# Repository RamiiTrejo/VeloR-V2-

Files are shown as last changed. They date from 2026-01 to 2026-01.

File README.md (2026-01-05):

## VeloR-V2

 Velo será un Robot seguidor de Líneas con una turbina integrada para una mayor agilidad, tambien llevara una regleta de 16 Sensores QRE1113, para una mejor lectura de la pista para lograr competir en la categoria de Carreras Pro de la LNR

<table>
<tr>
<td  colspan="2">  </td>
</tr>
<tr>
<td> 
 </td>
<td> 
 </td>
</tr>
</table>

## 🛠️🧰COMPONENTES
los componentes que utilizara este robot son
- ESP32 embebido
- Motores profast de 3600 RPM
- Ruedas JS2124
- Puentes H TA6586
- Motor Brushless/Coreless como Turbina
- Regleta De 16 [sensores QRE1113](https://github.com/RamiiTrejo/Array-16-Sensors)

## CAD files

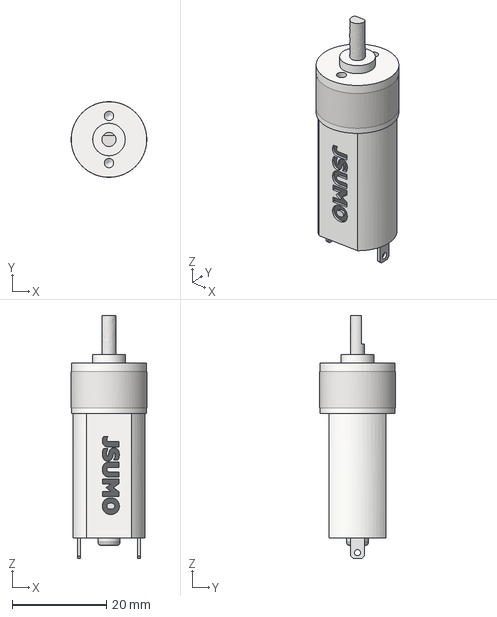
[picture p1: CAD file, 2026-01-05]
Hardware veloR V2/3d Files VeloR/Profast-dc-motor.igs
16.0 x 16.0 x 51.5 mm

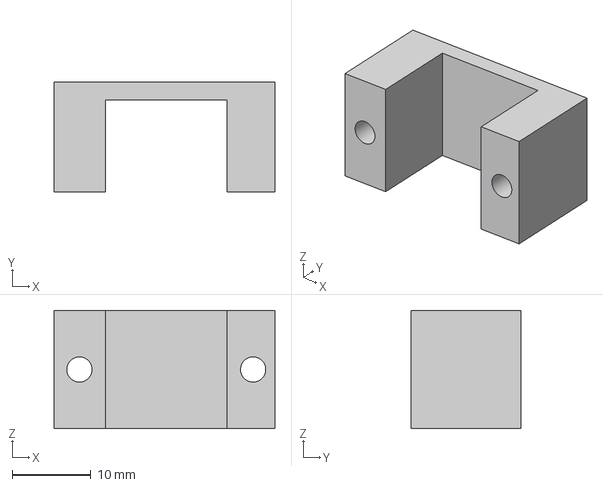
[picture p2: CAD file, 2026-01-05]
Hardware veloR V2/3d Files VeloR/bracket profast 3600rpm.step
28.1 x 14.0 x 15.0 mm

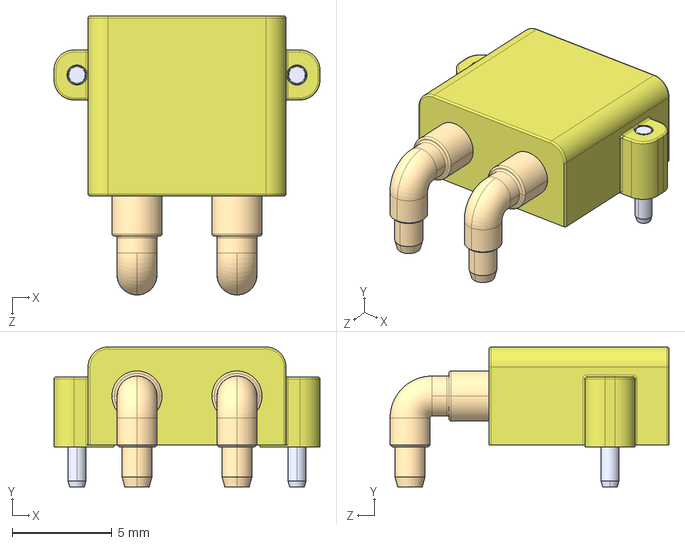
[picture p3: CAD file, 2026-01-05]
Hardware veloR V2/3d Files VeloR/XT30PW-M.step
13.3 x 7.00 x 14.0 mm

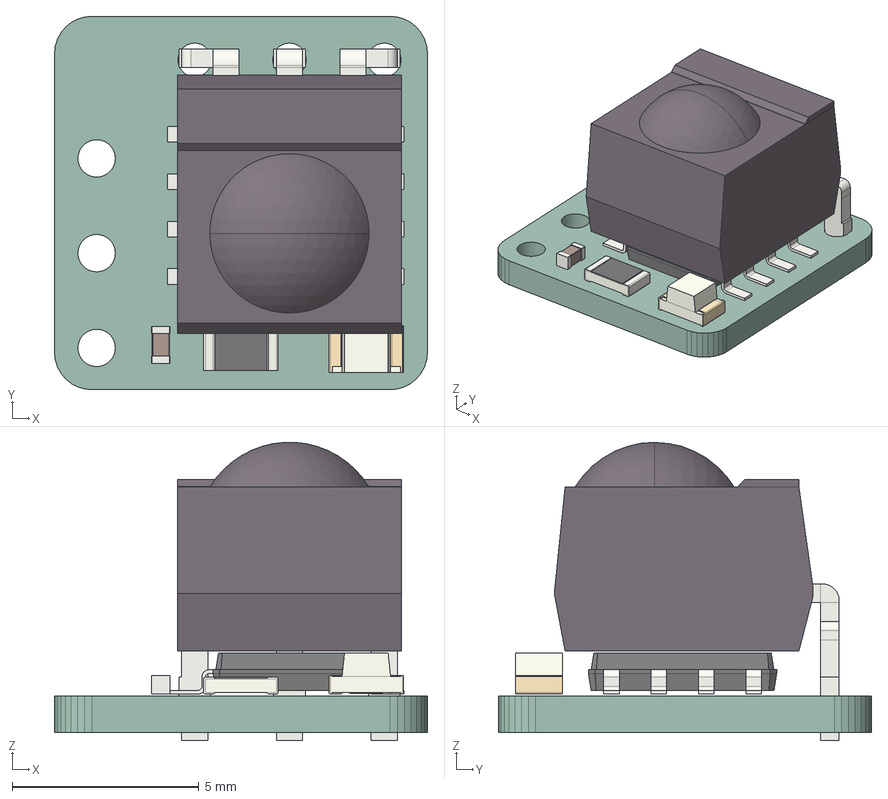
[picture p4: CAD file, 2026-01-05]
Hardware veloR V2/3d Files VeloR/IRStart - Module.step
10.0 x 10.0 x 8.00 mm
PCB

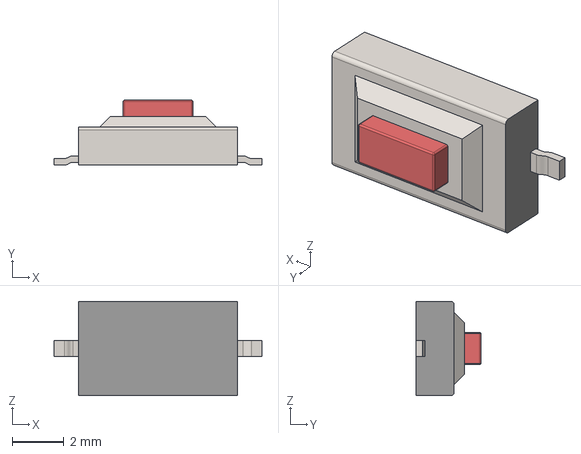
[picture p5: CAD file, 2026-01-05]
Hardware veloR V2/3d Files VeloR/BTN_SMD_3x6x2.5mm.step
8.05 x 2.51 x 3.66 mm

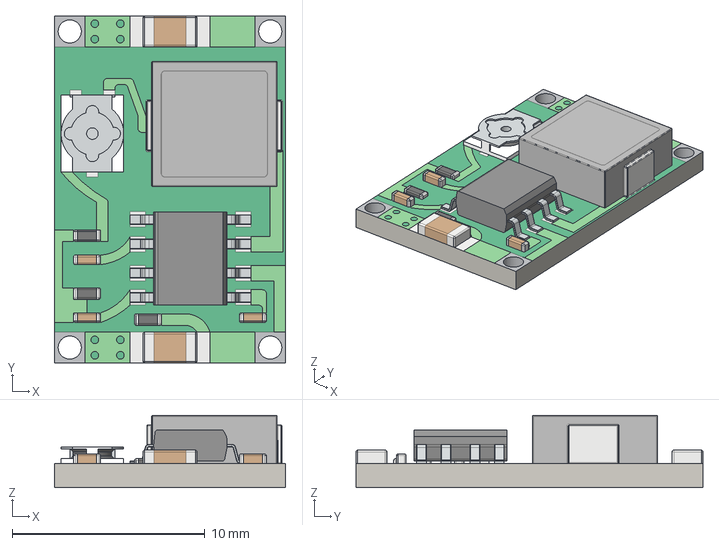
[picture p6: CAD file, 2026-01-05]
Hardware veloR V2/3d Files VeloR/Mini360.step
12.0 x 18.0 x 3.75 mm

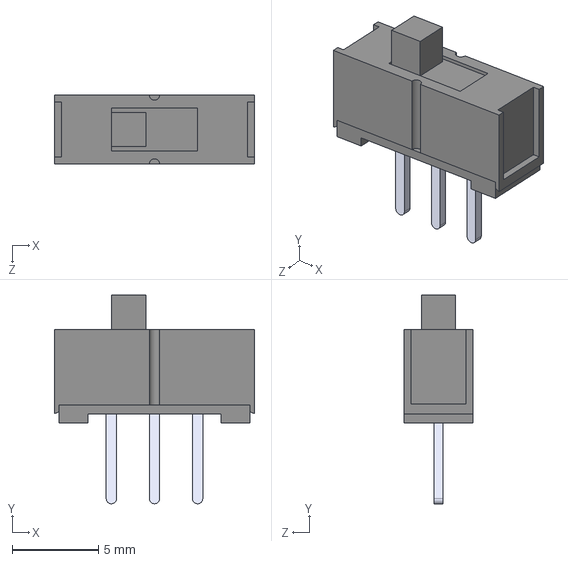
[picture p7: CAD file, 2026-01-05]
Hardware veloR V2/3d Files VeloR/MINI-SPDT-SW--3DModel-STEP-56544.STEP
11.6 x 12.1 x 4.00 mm

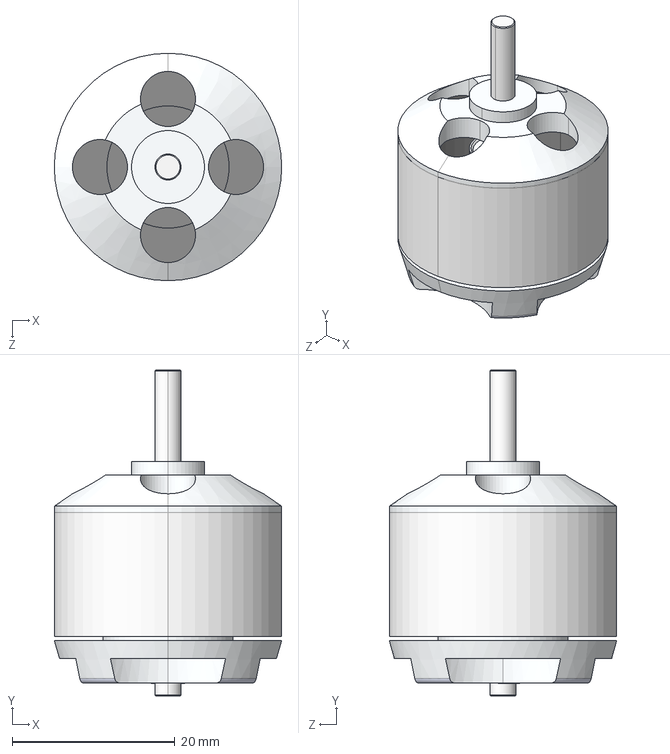
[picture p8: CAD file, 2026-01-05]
Hardware veloR V2/3d Files VeloR/Motor_BLDC_2212,6T_2200KV.STEP
27.9 x 40.0 x 27.9 mm

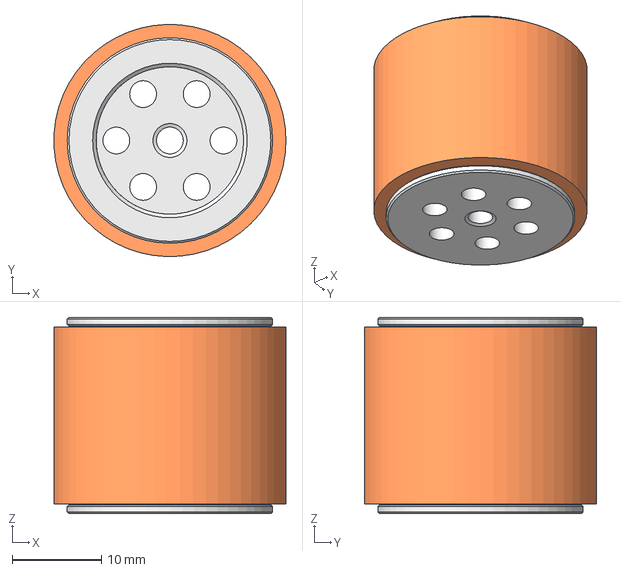
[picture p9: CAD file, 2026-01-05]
Hardware veloR V2/3d Files VeloR/Rueda_JS2622.stp
26.0 x 26.0 x 22.0 mm
JS2622
Goma JS2622

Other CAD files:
Hardware veloR V2/3d Files VeloR/Profast-dc-motor.x_t

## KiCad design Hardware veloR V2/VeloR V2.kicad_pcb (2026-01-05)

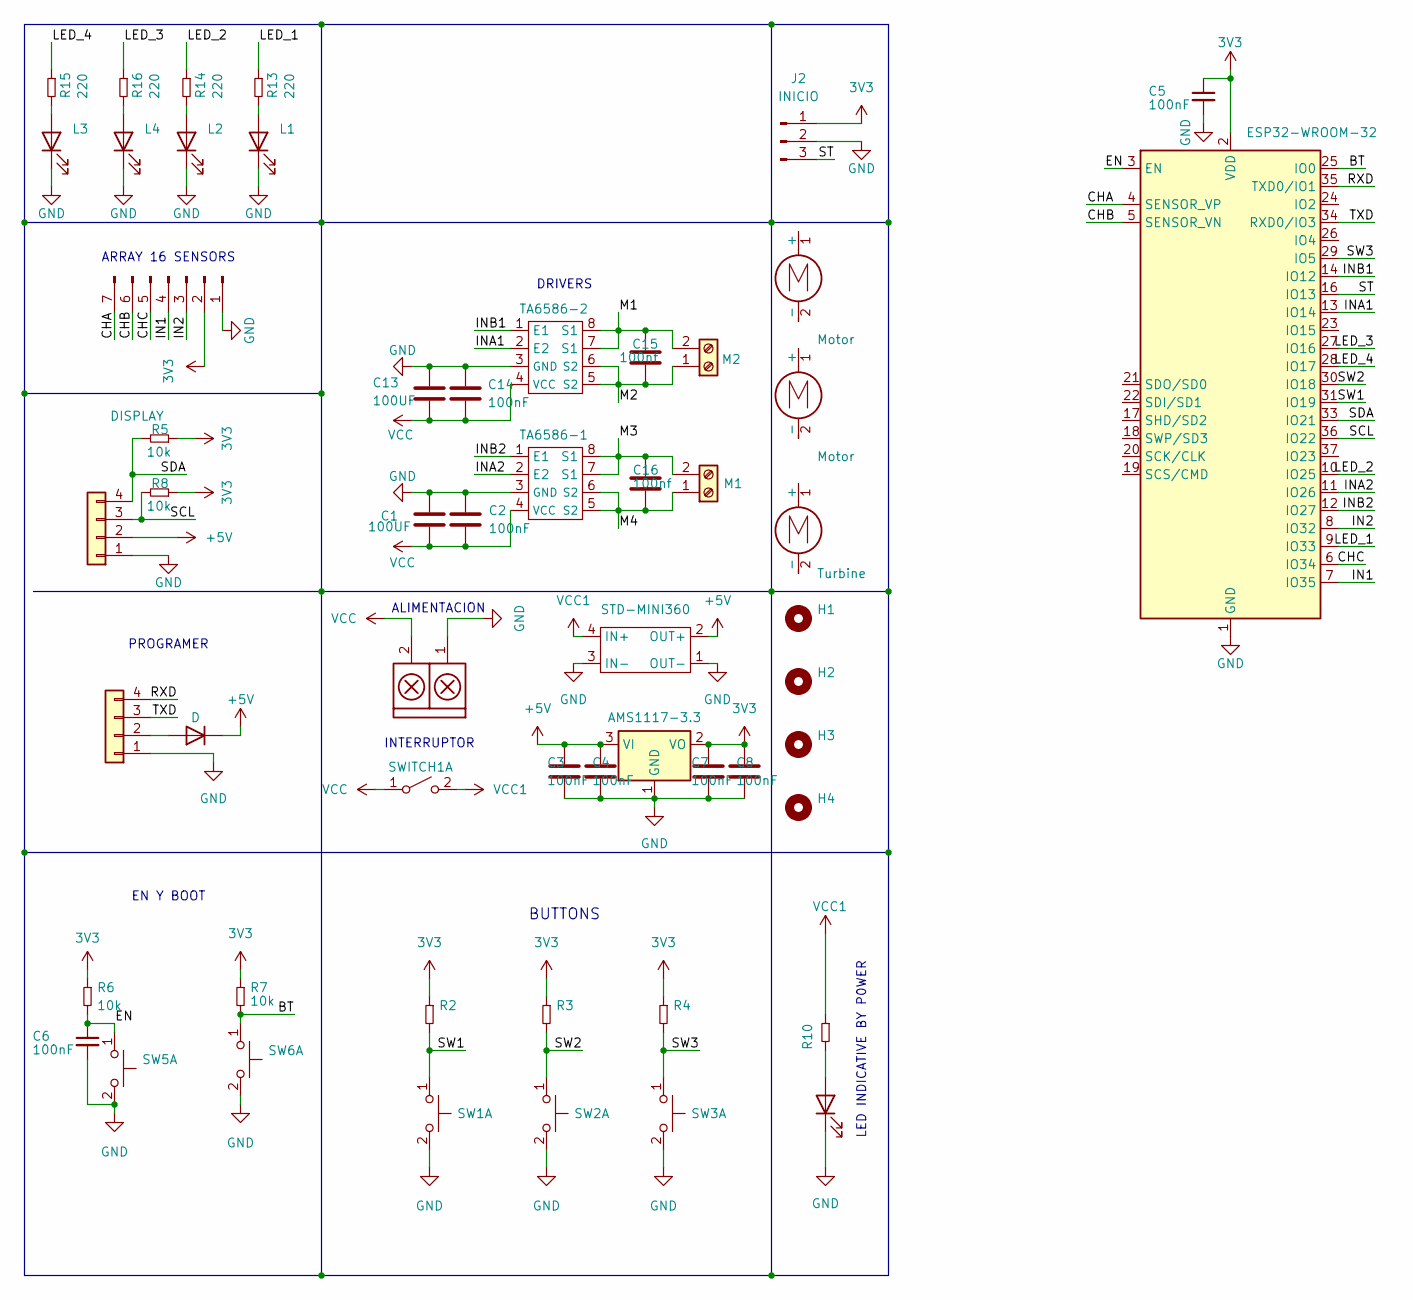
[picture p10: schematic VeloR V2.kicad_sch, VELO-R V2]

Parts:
Alimentacion1: TB_1X2; AMASS_XT30U-M_1x02_P5.0mm_Vertical
C1, C13: 100UF; CP_EIA-7343-20_Kemet-V
C2, C3, C4, C5, C6, C7, C8, C14: 100nF; C_0805_2012Metric_Pad1.18x1.45mm_HandSolder
C15, C16: 100nf; C_0805_2012Metric_Pad1.18x1.45mm_HandSolder
D1: D; D_SMA
D2: LED; LED_1206_3216Metric_Pad1.42x1.75mm_HandSolder
H1, H2, H3, H4: MountingHole; MountingHole_3.2mm_M3_DIN965
J1: Conn_01x07_Pin; PinHeader_1x07_P2.54mm_Horizontal
J2: INICIO; PinHeader_1x03_P2.54mm_Vertical
J3: DISPLAY; 128x64OLED
J5: DISPLAY; PinHeader_1x04_P2.54mm_Horizontal
L1, L2, L3, L4: LED; LED_0805_2012Metric_Pad1.15x1.40mm_HandSolder
M1: M1; JST_XH_B2B-XH-A_1x02_P2.50mm_Vertical
M2: M2; JST_XH_B2B-XH-A_1x02_P2.50mm_Vertical
M4, M6: Motor; motor 3600rpm
M5: Turbine; Turbina
R2, R3, R4, R5, R6, R7, R8, R10: 10k; R_0805_2012Metric_Pad1.20x1.40mm_HandSolder
R13, R14, R15, R16: 220; R_0805_2012Metric_Pad1.20x1.40mm_HandSolder
STD-MINI360: STEP DOWN MINI 360
SW1, SW2, SW3, SW5, SW6: SW_Push_Dual_x2; BTN_SMD_3x6x2.5mm
SWITCH1: SW_DPST_x2; PinHeader_1x03_P2.54mm_Vertical
TA6586-1, TA6586-2: DIP-8_W7.62mm
U1: AMS1117-3.3; SOT-223-3_TabPin2
U3: ESP32-WROOM-32

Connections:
3V3: C5.1, C7.1, C8.1, J1.2, J2.1, R2.1, R3.1, R4.1, R5.1, R6.1, R7.1, R8.1, U1.2 (VO), U3.2 (VDD)
+5V: C3.1, C4.1, D1.1 (K), J3.2, STD-MINI360.2 (OUT+), U1.3 (VI)
/BT: R7.2, SW6.1 (C), U3.25 (IO0)
/CHA: J1.7, U3.4 (SENSOR_VP)
/CHB: J1.6, U3.5 (SENSOR_VN)
/CHC: J1.5, U3.6 (IO34)
/EN: C6.1, R6.2, SW5.1 (C), U3.3 (EN)
/IN1: J1.4, U3.7 (IO35)
/IN2: J1.3, U3.8 (IO32)
/INA1: TA6586-2.2 (E2), U3.13 (IO14)
/INA2: TA6586-1.2 (E2), U3.11 (IO26)
/INB1: TA6586-2.1 (E1), U3.14 (IO12)
/INB2: TA6586-1.1 (E1), U3.12 (IO27)
/LED_1: R13.1, U3.9 (IO33)
/LED_2: R14.1, U3.10 (IO25)
/LED_3: R16.1, U3.27 (IO16)
/LED_4: R15.1, U3.28 (IO17)
/M1: C15.1, M2.2, TA6586-2.7 (S1), TA6586-2.8 (S1)
/M2: C15.2, M2.1, TA6586-2.5 (S2), TA6586-2.6 (S2)
/M3: C16.1, M1.2, TA6586-1.7 (S1), TA6586-1.8 (S1)
/M4: C16.2, M1.1, TA6586-1.5 (S2), TA6586-1.6 (S2)
/RXD: J5.4, U3.35 (TXD0/IO1)
/SCL: J3.3, R8.2, U3.36 (IO22)
/SDA: J3.4, R5.2, U3.33 (IO21)
/ST: J2.3, U3.16 (IO13)
/SW1: R2.2, SW1.1 (C), U3.31 (IO19)
/SW2: R3.2, SW2.1 (C), U3.30 (IO18)
/SW3: R4.2, SW3.1 (C), U3.29 (IO5)
/TXD: J5.3, U3.34 (RXD0/IO3)
GND: Alimentacion1.1, C1.1, C2.1, C3.2, C4.2, C5.2, C6.2, C7.2, C8.2, C13.1, C14.1, D2.1 (K), J1.1, J2.2, J3.1, J5.1, L1.1 (K), L2.1 (K), L3.1 (K), L4.1 (K), STD-MINI360.1 (OUT-), STD-MINI360.3 (IN-), SW1.2 (D), SW2.2 (D), SW3.2 (D), SW5.2 (D), SW6.2 (D), TA6586-1.3 (GND), TA6586-2.3 (GND), U1.1 (GND), U3.1 (GND), U3.15 (GND), U3.38 (GND), U3.39 (GND)
unnamed: D1.2 (A), J5.2
unnamed: D2.2 (A), R10.2
unnamed: L1.2 (A), R13.2
unnamed: L2.2 (A), R14.2
unnamed: L3.2 (A), R15.2
unnamed: L4.2 (A), R16.2
VCC: Alimentacion1.2, C1.2, C2.2, C13.2, C14.2, SWITCH1.1 (A), TA6586-1.4 (VCC), TA6586-2.4 (VCC)
VCC1: R10.1, STD-MINI360.4 (IN+), SWITCH1.2 (B)

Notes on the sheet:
ALIMENTACION
INTERRUPTOR
BUTTONS
LED INDICATIVE BY P0WER
DRIVERS
ARRAY 16 SENSORS
EN Y BOOT
PROGRAMER

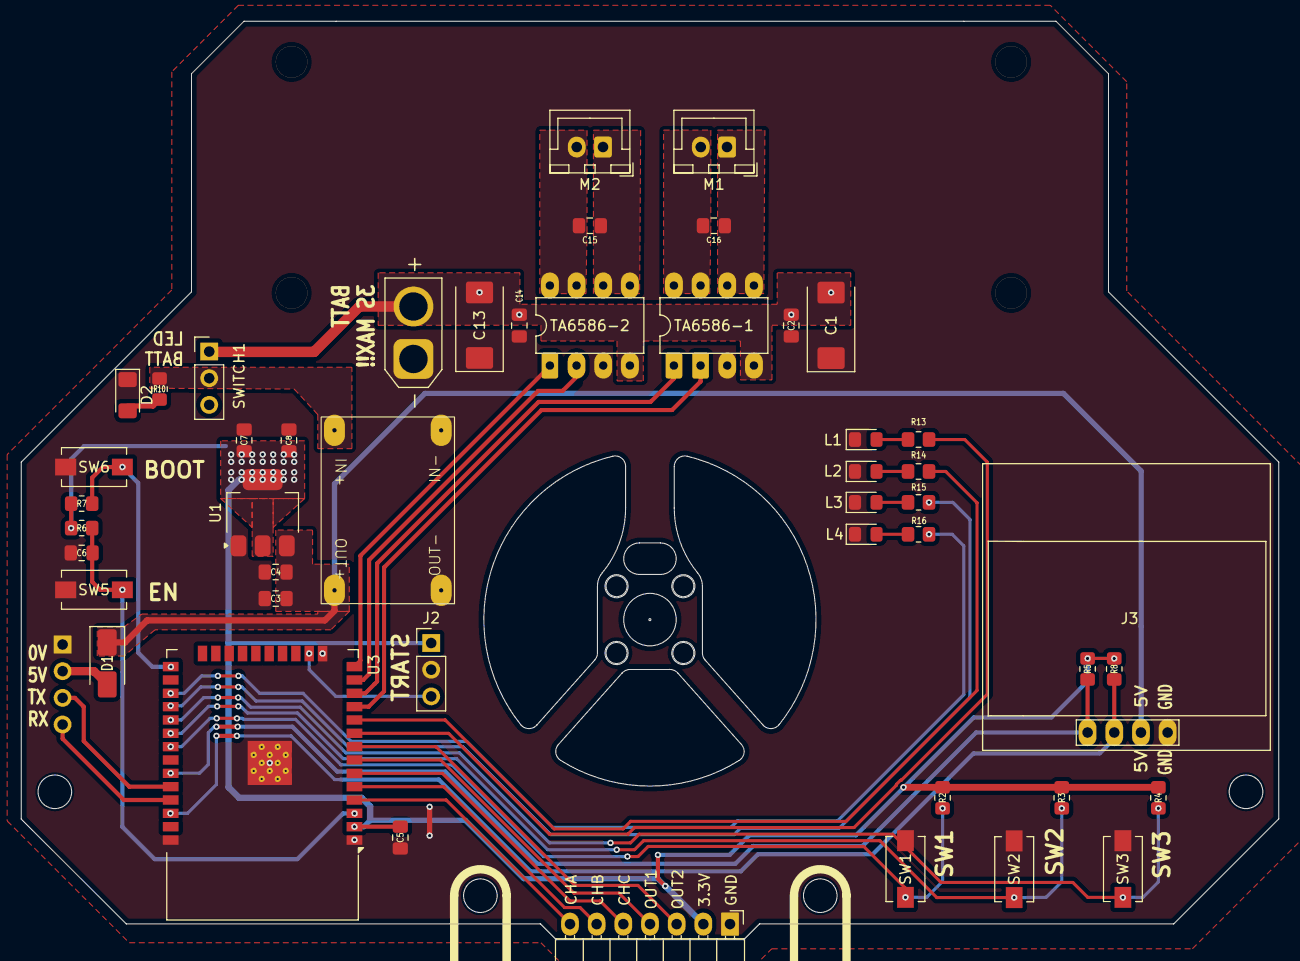
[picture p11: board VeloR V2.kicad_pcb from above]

Board: 2 copper layers, 119.8 x 87.5 mm, 57 parts (1 on the bottom side), 38 nets.

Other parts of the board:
H3#2, H4#2: MountingHole; MountingHole_3.2mm_M3_DIN965
